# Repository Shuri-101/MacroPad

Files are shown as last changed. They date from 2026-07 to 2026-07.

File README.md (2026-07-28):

# Fracture Pad (A macro pad project) 



## Description:
A macro Pad for use in CAD and general productivity + convenience, mainly for use in CAD... but up to you to decide what you want to use it for, I included an OLED screen to display things like animations or info like RAM usage.

## Features:
- 1.51 inch transparent oled screen
- 9 cherry MX switches
- Back lit RGB leds for each switch (SK6812 MINI-E)
- 3 EC11 rotary encoders
- 3D printed voronoi patterned **snap lock** case **NO SCREWS NEEDED for assembly of case** (only screws are needed for the mounting of the OLED driver board which are provided in the oled package bought from waveshare)
- **NO HEAT ISERTS REQUIRED** as the oled board can be mounted on 3D printed standoffs by just threading the screws on since not a high amount of strength is required for mounting of the driver board.
- 3D printed TPU feet to prevent the macro pad from sliding around.

## CAD model:

### Info:
The casing is made up of 3 main layers OLED cover --> Case Lid --> Case bottom. Things that should be 3D printed are Rotary encoder knobs, All casing layers and OLED driver board standoffs. The casing has a OLED cover so the OLED driver and screen can be removed from the PCB so it can be reused. YOU MUST solder the MX switches after putting the PCB into the case (bottom and lid) since the lid contains a key panel to support the MX switches.

"Note: Created in solidworks"

### OLED cover:


### Case Lid:


### Case bottom:


### View of PCB mounting:


### Exploded view:




## Schematic:





### Info:
- GPIO expander used to host the keyboard matrix allowing me to have 3 rotary encoders.
- Decoupling capacitors added for RGB LEDs and GPIO expander.
- Thru hole pads added for oled wires that connect to the oled driver board.

## PCB


### Info:
- 2 layer PCB with ground plane included.
- 113mm (width) x 86mm (length).
- M3 sized mounting holes for securing the PCB. (No screws are used for mounting of this PCB in the case)
- I recomend to get the manufacutre to assemble **ONLY THE SMD COMPONENTS** the PCB for you as i use SMD variants for diodes, capacitors and components to save space, unless you know how to do reflow soldering and have the equipment.
- There are some DRC errors but those should be fine to ignore as i think it should be fine to cut of a 0.1mm of a RGB LED pad.

## Firmware overview:

- Work in progress...

## BOM
- 9x SK6812MINI-E RGB LEDS.
- 9X Cherry MX keycaps.
- 85g of 3D printing filament (optional 3 colours and TPU feet)
- x10 MLCC ceramic capacitor 0.1uF
- x9 Cherry MX Mechanical Switches
- x1 XIAO RP2040 (MCU) 
- x1 MLCC ceramic 4.7uF (SMD)
- x1 330Ω resistor 
- x1 47 µF Electrolytic Capacitor
- x3 EC11 Rotary encoders
- x9 1N4148 Diodes (SMD variant)
- X1 PCF8574AT (GPIO expander) (SMD variant)

## Ai usage declaration:
Since this was my first PCB project i used ai extensively for research and learning how to design PCBs and how to use ki-cad. e.g. "How wide should this trace be" or  "What is a decoupling capacitor when should I use it? Does the GPIO expander need a decoupling capacitor..." **I ONLY USE AI TO LEARN**  like now i understand why decoupling capacitors are used and how they are connected and now i understand power traces like 5v should be wide and ground traces if needed should be wider to allow low resistance path... ill be happy to answer any questions regarding this. I also used AI during programming since i overcomplicated things for this board with an additional GPIO expander and 3 rotarty encoders so i kinda messed up during qmk codding so i used ai just to fix everything cause yk... it was so painful.......................... probably around 25% of the code.... i mean it should be................................................................. aaaaaaaaaaaaaaaaaaaaaaaaaaaaaaaaaaaaaaaaaaaaaaaaaaaaaaaaaaa

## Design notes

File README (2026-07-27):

#Fracture Pad (A macro pad project) 
A macro Pad for use in CAD and general productivity + convenience, mainly for use in CAD... but up to you to decide what you want to use it for, I included an OLED screen to display things like animations or info like RAM usage...
# Orpheuspad

Orpheuspad is a 4 key macropad with a rotary encoder, an OLED Display. It also has 2 WS2812B Leds, and uses QMK firmware

It serves as an example piece/reference for the hackpad YSWS, since it contains an implementation of every common part.

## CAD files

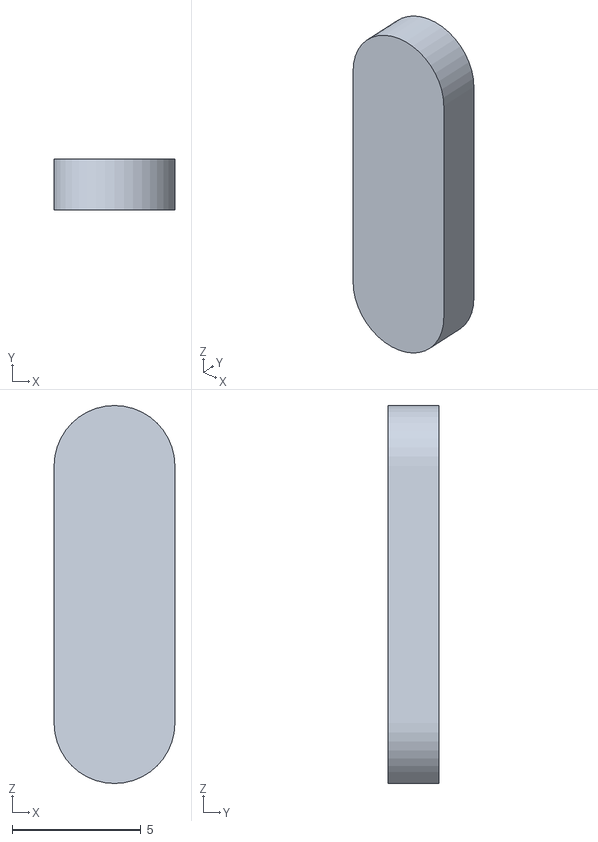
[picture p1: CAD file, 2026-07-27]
3D Printing Files/TPU feet.STL
4.70 x 2.00 x 14.7

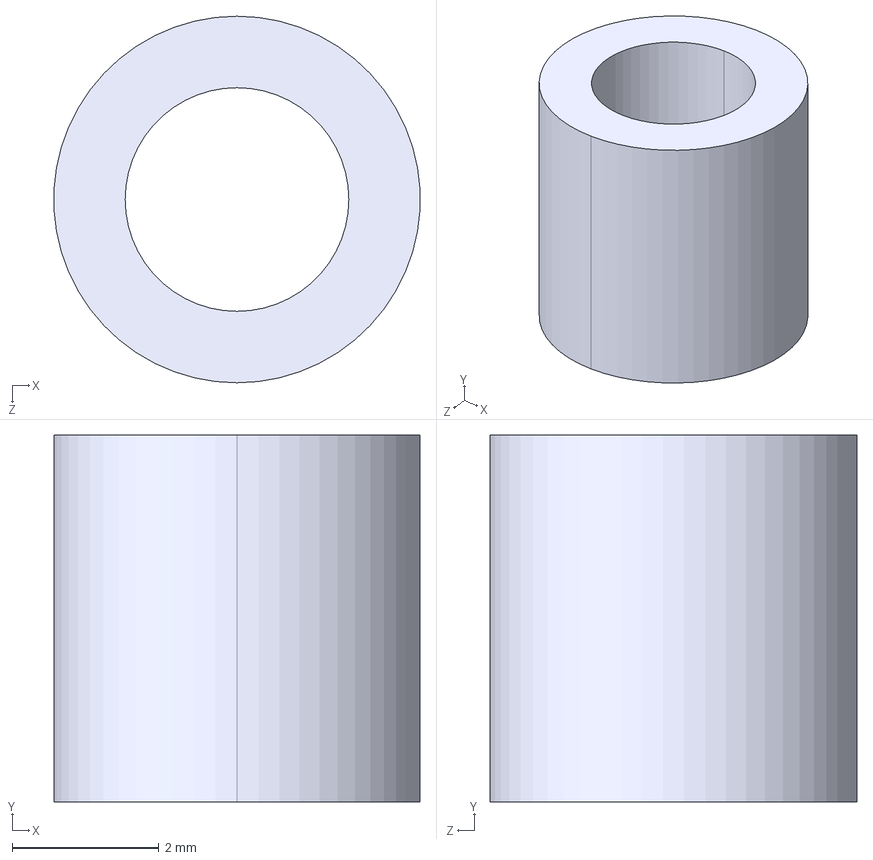
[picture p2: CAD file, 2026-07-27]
CAD-files/OLED standoff M3.STEP
4.99 x 5.00 x 5.00 mm

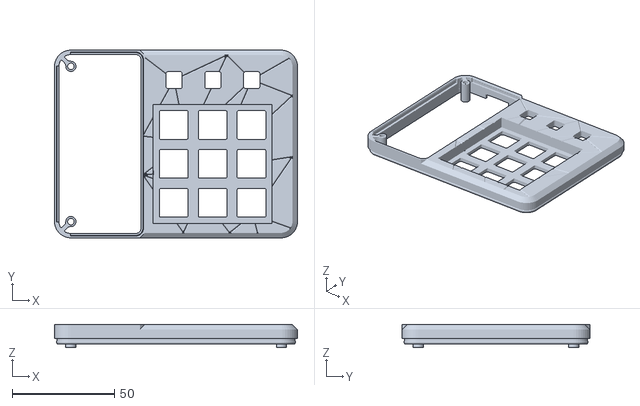
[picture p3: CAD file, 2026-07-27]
3D Printing Files/MacroPAD casing LID B.STL
118.9 x 91.9 x 11.4

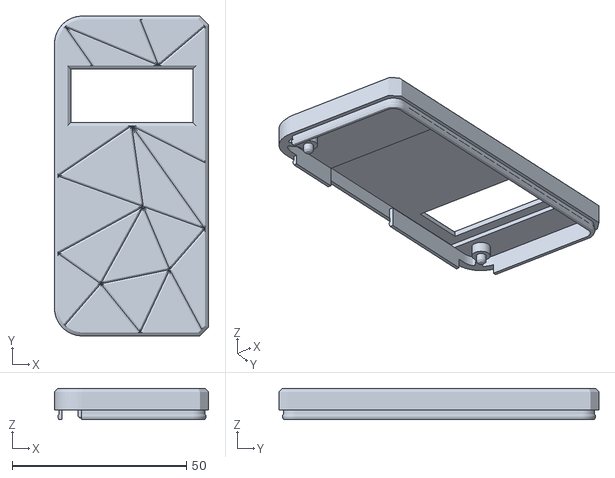
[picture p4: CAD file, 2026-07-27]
3D Printing Files/OLED cap.STL
44.2 x 91.9 x 8.95

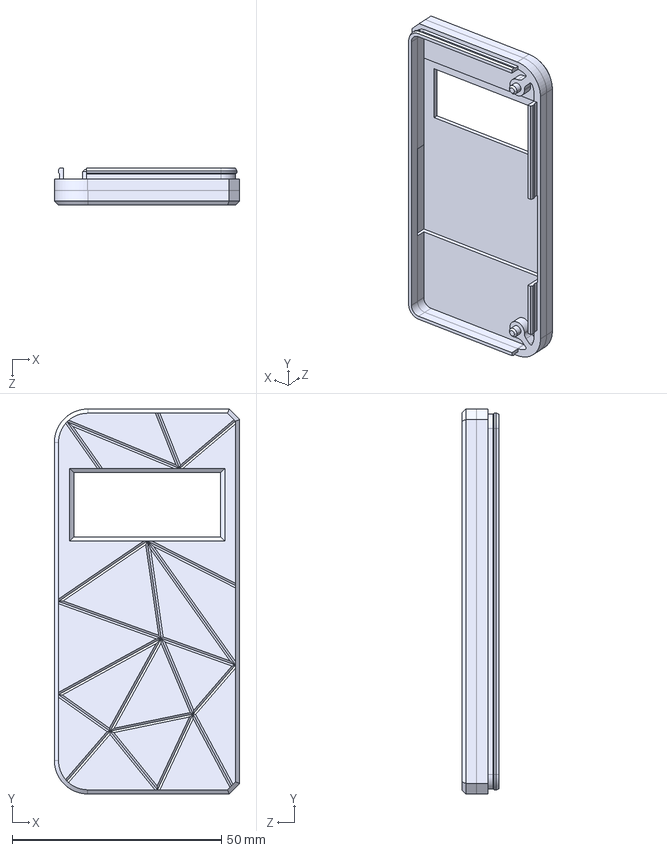
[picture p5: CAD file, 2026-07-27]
CAD-files/OLED cover.STEP
44.2 x 91.9 x 8.95 mm

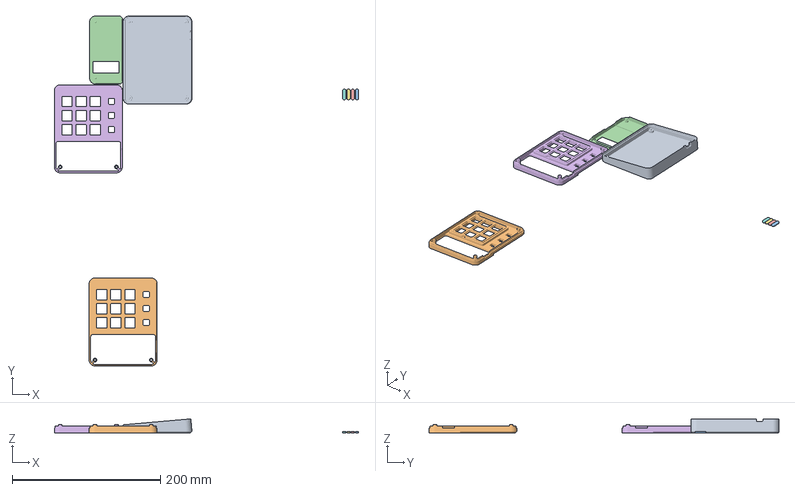
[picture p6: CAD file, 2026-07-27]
3D Printing Files/BAMBU LAB 3MF FILE MACRO PAD CASING.3mf
411.1 x 472.6 x 19.3 mm
MacroPAD casing BASE.STL
MacroPAD casing LID.STL
TPU feet.STL x 4
OLED cap.STL
MacroPAD casing LID B.STL

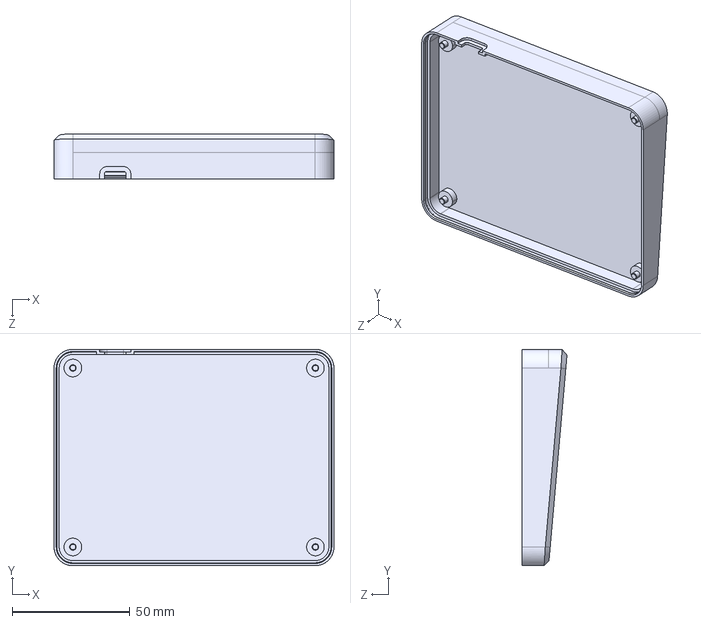
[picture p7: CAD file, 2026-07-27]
CAD-files/MacroPAD casing BASE.STEP
118.9 x 91.9 x 19.1 mm

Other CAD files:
CAD-files/MacroPAD casing LID.STEP
3D Printing Files/MacroPAD casing BASE.STL
3D Printing Files/MacroPAD casing LID.STL
3D Printing Files/OLED standoff M3.STL

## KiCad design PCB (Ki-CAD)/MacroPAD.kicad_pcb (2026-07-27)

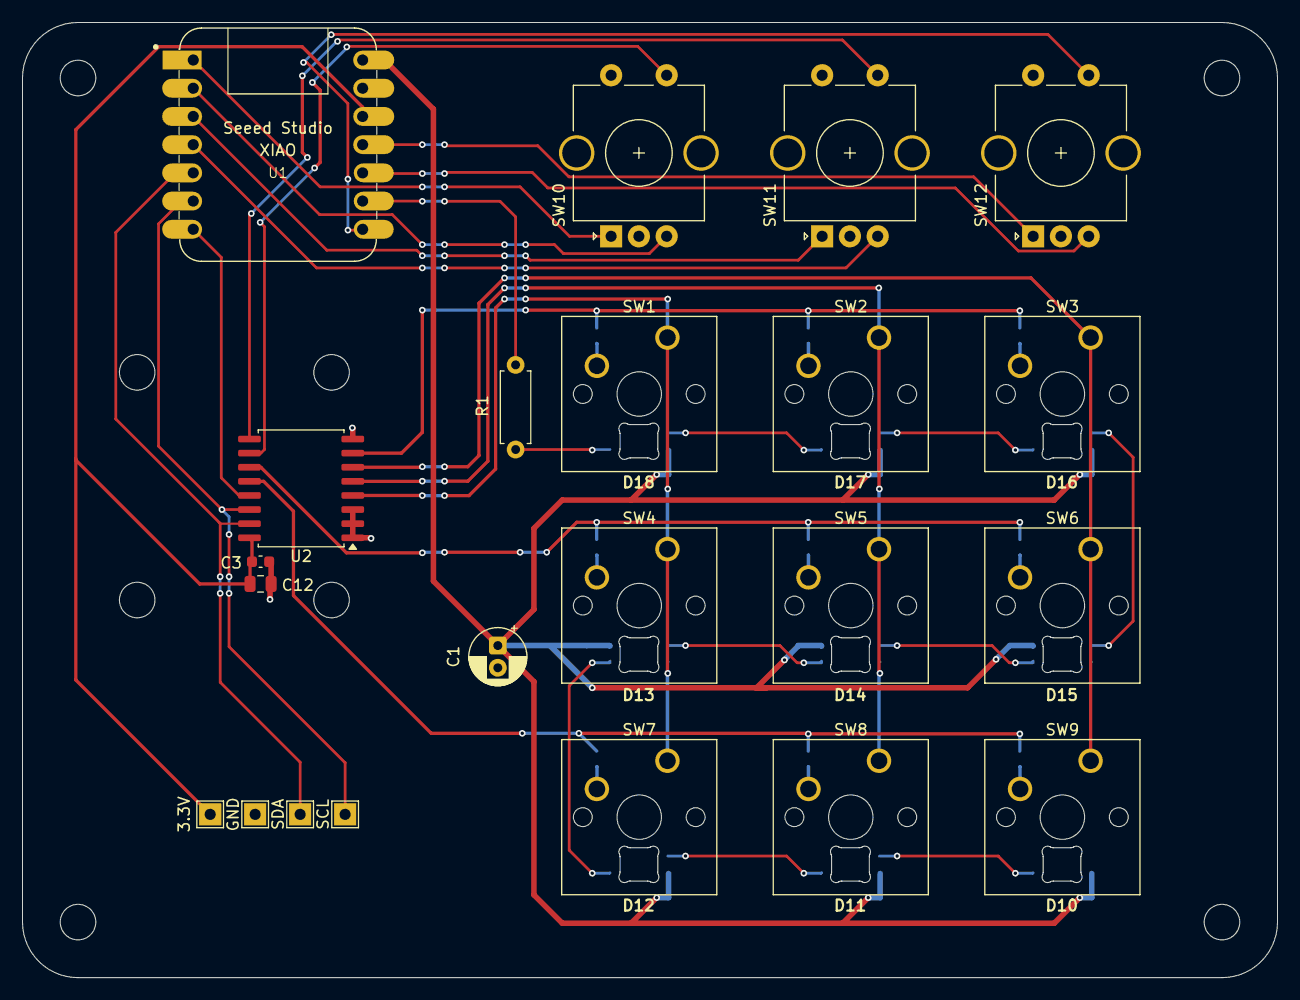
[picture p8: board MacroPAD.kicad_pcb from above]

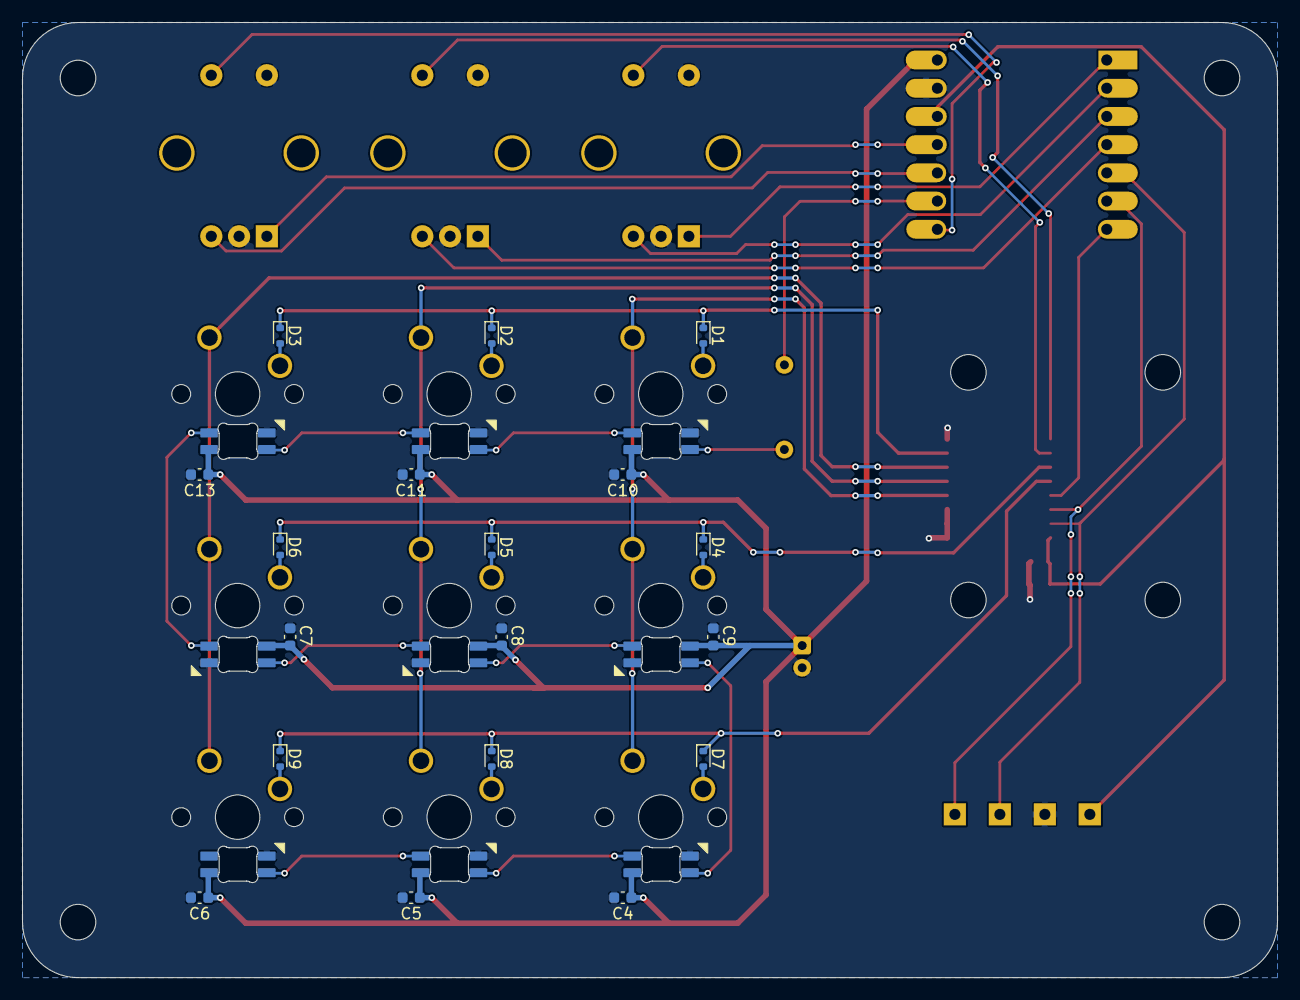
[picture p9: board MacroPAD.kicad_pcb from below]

Board: 2 copper layers, 113.0 x 86.0 mm, 49 parts (18 on the bottom side), 25 nets.

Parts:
3.3V: MountingHole_Pad; TestPoint_THTPad_2.0x2.0mm_Drill1.0mm
C1: 47uF; CP_Radial_D5.0mm_P2.00mm
C3, C4, C5, C6, C7, C8, C9, C10, C11, C13: 0.1uF; C_0603_1608Metric
C12: 4.7 µF; C_0805_2012Metric
D1, D2, D3, D4, D5, D6, D7, D8, D9: 1N4148WT; D_SOD-523
D10, D11, D12, D13, D14, D15, D16, D17, D18: SK6812MINI-E; SK6812MINI-E_fixed
GND: MountingHole_Pad; TestPoint_THTPad_2.0x2.0mm_Drill1.0mm
R1: 330R; R_Axial_DIN0207_L6.3mm_D2.5mm_P7.62mm_Horizontal
SCL: MountingHole_Pad; TestPoint_THTPad_2.0x2.0mm_Drill1.0mm
SDA: MountingHole_Pad; TestPoint_THTPad_2.0x2.0mm_Drill1.0mm
SW1, SW2, SW3, SW4, SW5, SW6, SW7, SW8, SW9: SW_Push; SW_Cherry_MX_1.00u_PCB
SW10, SW11: RotaryEncoder; RotaryEncoder_Alps_EC11E-Switch_Vertical_H20mm_CircularMoun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
SW12: RotaryEncoder_Switch; RotaryEncoder_Alps_EC11E-Switch_Vertical_H20mm_CircularMoun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
U1: MOUDLE-SEEEDUINO-XIAO; XIAO-Generic-Hybrid-14P-2.54-21X17.8MM
U2: PCF8574AT; SOIC-16W_7.5x10.3mm_P1.27mm

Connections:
3.3V: 3.3V.1, C3.1, C12.1, U1.12 (3V3), U2.16 (VDD)
5V: C1.1, C4.1, C5.1, C6.1, C7.1, C8.1, C9.1, C10.1, C11.1, C13.1, D10.1 (VDD), D11.1 (VDD), D12.1 (VDD), D13.1 (VDD), D14.1 (VDD), D15.1 (VDD), D16.1 (VDD), D17.1 (VDD), D18.1 (VDD), U1.14 (5V)
C1: SW1.1, SW4.1, SW7.1, U2.4 (P0)
C2: SW2.1, SW5.1, SW8.1, U2.5 (P1)
C3: SW3.1, SW6.1, SW9.1, U2.6 (P2)
GND: C1.2, C3.2, C4.2, C5.2, C6.2, C7.2, C8.2, C9.2, C10.2, C11.2, C12.2, C13.2, D10.3 (VSS), D11.3 (VSS), D12.3 (VSS), D13.3 (VSS), D14.3 (VSS), D15.3 (VSS), D16.3 (VSS), D17.3 (VSS), D18.3 (VSS), GND.1, SW10.C, SW10.S2, SW11.C, SW11.S2, SW12.C, SW12.S2, U1.13 (GND), U2.1 (A0), U2.2 (A1), U2.3 (A2), U2.8 (GND)
INT: U1.7 (PB08_A6_D6_TX), U2.13 (~INT)
Input A1: SW10.A, U1.1 (PA02_A0_D0)
Input A2: SW11.A, U1.3 (PA10_A2_D2)
Input A3: SW12.A, U1.11 (PA6_A10_D10_MOSI)
Input B1: SW10.B, U1.2 (PA4_A1_D1)
Input B2: SW11.B, U1.4 (PA11_A3_D3)
Input B3: SW12.B, U1.10 (PA5_A9_D9_MISO)
unnamed: D1.2 (A), D2.2 (A), D3.2 (A), D4.2 (A), D5.2 (A), D6.2 (A), D7.2 (A), D8.2 (A), D9.2 (A), SW1.2, SW2.2, SW3.2, SW4.2, SW5.2, SW6.2, SW7.2, SW8.2, SW9.2
unnamed: D18.4 (DIN), R1.2
unnamed: D10.2 (DOUT), D10.4 (DIN), D11.2 (DOUT), D11.4 (DIN), D12.2 (DOUT), D12.4 (DIN), D13.2 (DOUT), D13.4 (DIN), D14.2 (DOUT), D14.4 (DIN), D15.2 (DOUT), D15.4 (DIN), D16.2 (DOUT), D16.4 (DIN), D17.2 (DOUT), D17.4 (DIN), D18.2 (DOUT)
R1: D1.1 (K), D2.1 (K), D3.1 (K), U2.7 (P3)
R2: D4.1 (K), D5.1 (K), D6.1 (K), U2.11 (P6)
R3: D7.1 (K), D8.1 (K), D9.1 (K), U2.12 (P7)
RGB_DATA: R1.1, U1.9 (PA7_A8_D8_SCK)
S1A: SW10.S1A, U2.10 (P5)
S1B: SW11.S1B, U2.9 (P4)
S1C: SW12.S1C (S1), U1.8 (PB09_A7_D7_RX)
SCL: SCL.1, U1.6 (PA9_A5_D5_SCL), U2.14 (SCL)
SDA: SDA.1, U1.5 (PA8_A4_D4_SDA), U2.15 (SDA)

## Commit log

2026-07-02 Create BOM
    BOM of all the components / materials
2026-07-03 Update BOM
2026-07-27 Create CAD files
2026-07-27 Uploaded stl and 3mf files
    [BAMBU LAB 3MF FILE MACRO PAD CASING.3mf, MacroPAD casing BASE.STL, MacroPAD casing LID B.STL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]
2026-07-27 PCB ki cad files
    [MacroPAD.kicad_pcb, MacroPAD.kicad_sch]
2026-07-27 Ki cad sym and foottprints
2026-07-27 STEP component file upload
    [MacroPAD casing BASE.STEP, MacroPAD casing LID.STEP, OLED cover.STEP]
2026-07-27 OLED driver board m3 standoffs (not included in 3mf)
    [OLED standoff M3.STEP, OLED standoff M3.STL]
